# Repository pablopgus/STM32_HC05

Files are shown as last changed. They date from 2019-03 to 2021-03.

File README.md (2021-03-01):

# STM32_HC05
This is a PCB board designed in KiCAD which implements a STM32F746VGT6 microcontroller exposing the following pins and internal connections. All of the GPIO pins support timer peripheral output, for a more detailed view of the potential PIN function, check the STM32F7 datasheet using name as a reference. Please read [STM32F7 Reference page](https://www.st.com/en/microcontrollers-microprocessors/stm32f7-series.html) and [Getting Started Guide](https://www.st.com/resource/en/user_manual/dm00180213-getting-started-with-stm32cubef7-mcu-package-for-stm32f7-series-stmicroelectronics.pdf).

This board includes a [HC-05 Bluetooth module](https://components101.com/wireless/hc-05-bluetooth-module)  which exposes a serial port interface over bluetooth as a direct link with the microcontroller. The bluetooth module is switched on/off with a transistor switch controlled by a microcontroller pin. 

## Board Design
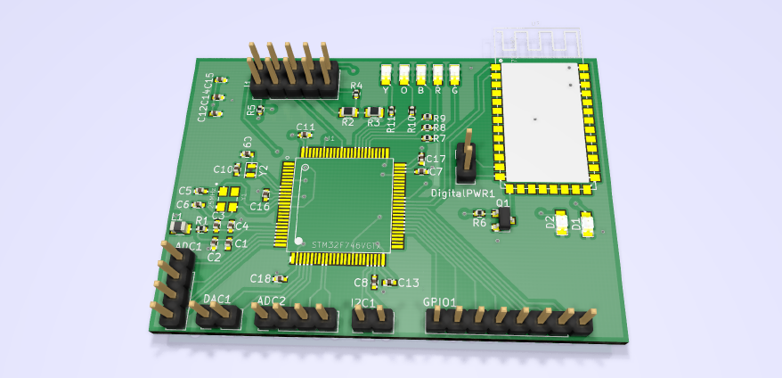
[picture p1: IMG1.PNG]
PCB Design


## Pinout
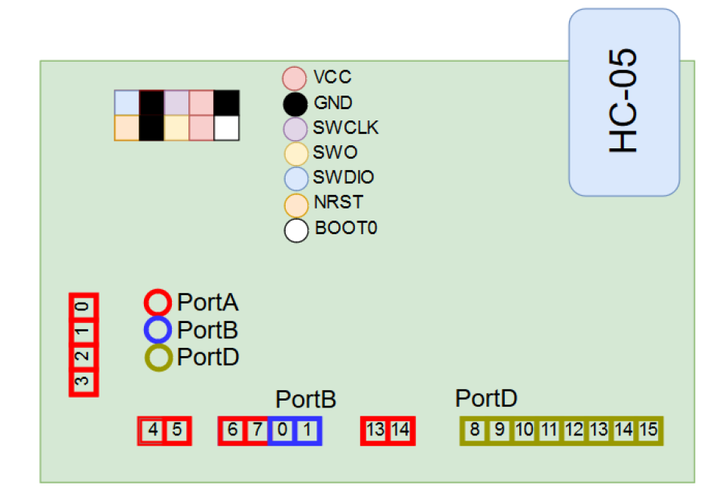
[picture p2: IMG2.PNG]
Pinout


## Pin Function

| Name | Pin | Extra Functions |
| :---: |:---:| :---: |
| PA0 | 22 | ADC0, UART4_TX, USART2_CTS |
| PA1 | 23 | ADC1, UART4_RX, USART2_RTS |
| PA2 | 24 | ADC2, USART2_TX |
| PA3 | 25 | ADC3, USART2_RX |
| PA4 | 28 | ADC4, USART2_CLK |
| PA5 | 29 | ADC5, SPI1_CLK |
| PA6 | 30 | ADC6, SPI1_MISO |
| PA7 | 31 | ADC7, SPI1_MOSI |
| PB0 | 34 | ADC8 |
| PB1 | 35 | ADC9 |
| PB10 | 46 | I2C2_CLK |
| PB11 | 47 | I2C2_SDA |
| PD8 | 55 | USART3_TX |
| PD9 | 56 | USART3_RX |
| PD10 | 57 | USART3_CLK |
| PD11 | 58 | USART3_CTS |
| PD12 | 59 | USART3_RTS |
| PD13 | 60 | |
| PD14 | 61 | |
| PD15 | 62 | |
| PD0 | 81 | Green LED |
| PD1 | 82 | Red LED |
| PD2 | 83 | Blue LED |
| PD3 | 84 | Orange LED |
| PD4 | 85 | Yellow LED |
| PC6 | 63 | HC-05 UART RX |
| PC7 | 64 | HC-05 UART TX |
| PC8 | 65 | HC-05 BT KEY |
| PE12 | 42 | Bluetooth Enable |

## Programming Interface
The programming and power port is located on the upper left section of the board. The flashing debugging must be performed using a ST-Link/v2 debugger or STM32FX evaluation board (Discovery, Nucleo, etc ...). LEDs are connected to GPIO (PD0-4), bluetooth module is connected to UART6 port and the bluetooth module on/off actuation is driven by GPIO PE12. Further information on programming and the specific pin functions can be found on the STM32F7 datasheet, and the HC-05 bluetooth module reference guide.

# Code Examples
The following 4 files form the required interface to program and operate the Bluetooth module via the UART peripheral of the STM32F7.
## bluetooth.h
```C
#ifndef __bluetooth_H
#define __bluetooth_H
#ifdef __cplusplus
 extern "C" {
#endif

/* Includes ------------------------------------------------------------------*/
#include "stm32f7xx_hal.h"
#include "stdlib.h"
#include <stdio.h>
#include <string.h>
#include "gpio.h"

void BT_isAlive(void);
void BT_setNameMixcell(void);
void BT_clearPaired(void);
void BT_setMaster(void);
void BT_setSlave(void);
void BT_setCOM(void);
void BT_Reset(void);	
void BT_Restore(void);	
void BT_SendTest(void);
void BT_CMode(void);
void BT_Init_UART(void);
	 
#ifdef __cplusplus
}
#endif
#endif /*__ bluetooth_H */
```
## bluetooth.c
```C
#include "bluetooth.h"

extern UART_HandleTypeDef UART;

extern char data_rx[32];
extern char rx_data[8];			/* Buffer used for UART */

void BT_isAlive(void)
{
	char data_tx[4] = "AT\r\n";
	memset(data_rx, 0x00, 32);
	HAL_UART_Transmit(&UART, (uint8_t *) data_tx, 4, 1000);
	HAL_UART_Receive(&UART, (uint8_t *) data_rx, 24, 1000);
}

void BT_setName(void)
{
	// TODO Set Bluetooth name: MY_NAME.
	char data_tx[17] = "AT+NAME=MY_NAME\r\n";
	memset(data_rx, 0x00, 32);
	HAL_UART_Transmit(&UART, (uint8_t *) data_tx, 17, 500);
	HAL_UART_Receive(&UART, (uint8_t *) data_rx, 24, 500);
}

void BT_setMaster(void)
{
	char data_tx[11] = "AT+ROLE=1\r\n";
	memset(data_rx, 0x00, 32);
	HAL_UART_Transmit(&UART, (uint8_t *) data_tx, 11, 500);
	HAL_UART_Receive(&UART, (uint8_t *) data_rx, 24, 500);
}

void BT_setSlave(void)
{
	char data_tx[11] = "AT+ROLE=0\r\n";
	memset(data_rx, 0x00, 32);
	HAL_UART_Transmit(&UART, (uint8_t *) data_tx, 11, 500);
	HAL_UART_Receive(&UART, (uint8_t *) data_rx, 24, 500);
}

void BT_Reset(void)
{
	char data_tx[10] = "AT+RESET\r\n";
	memset(data_rx, 0x00, 32);
	HAL_UART_Transmit(&UART, (uint8_t *) data_tx, 10, 500);
	HAL_UART_Receive(&UART, (uint8_t *) data_rx, 24, 500);
}

void BT_Restore(void)
{
	char data_tx[9] = "AT+ORGL\r\n";
	memset(data_rx, 0x00, 32);
	HAL_UART_Transmit(&UART, (uint8_t *) data_tx, 9, 500);
	HAL_UART_Receive(&UART, (uint8_t *) data_rx, 32, 500);
}

void BT_clearPaired(void)
{
	char data_tx[10] = "AT+RMAAD\r\n";
	memset(data_rx, 0x00, 32);
	HAL_UART_Transmit(&UART, (uint8_t *) data_tx, 10, 500);
	HAL_UART_Receive(&UART, (uint8_t *) data_rx, 24, 500);
}

void BT_setCOM(void)
{
	char data_tx[20] = "AT+UART=115200,0,0\r\n";
	memset(data_rx, 0x00, 32);
	HAL_UART_Transmit(&UART, (uint8_t *) data_tx, 20, 500);
	HAL_UART_Receive(&UART, (uint8_t *) data_rx, 24, 500);
}
```
## usart.h
```C
/**
  ******************************************************************************
  * File Name          : UART.h
  * Date               : 13/04/2015 14:34:07
  * Description        : This file provides code for the configuration
  *                      of the USART instances.
  ******************************************************************************
  *
  * COPYRIGHT(c) 2015 STMicroelectronics
  *
  * Redistribution and use in source and binary forms, with or without modification,
  * are permitted provided that the following conditions are met:
  *   1. Redistributions of source code must retain the above copyright notice,
  *      this list of conditions and the following disclaimer.
  *   2. Redistributions in binary form must reproduce the above copyright notice,
  *      this list of conditions and the following disclaimer in the documentation
  *      and/or other materials provided with the distribution.
  *   3. Neither the name of STMicroelectronics nor the names of its contributors
  *      may be used to endorse or promote products derived from this software
  *      without specific prior written permission.
  *
  * THIS SOFTWARE IS PROVIDED BY THE COPYRIGHT HOLDERS AND CONTRIBUTORS "AS IS"
  * AND ANY EXPRESS OR IMPLIED WARRANTIES, INCLUDING, BUT NOT LIMITED TO, THE
  * IMPLIED WARRANTIES OF MERCHANTABILITY AND FITNESS FOR A PARTICULAR PURPOSE ARE
  * DISCLAIMED. IN NO EVENT SHALL THE COPYRIGHT HOLDER OR CONTRIBUTORS BE LIABLE
  * FOR ANY DIRECT, INDIRECT, INCIDENTAL, SPECIAL, EXEMPLARY, OR CONSEQUENTIAL
  * DAMAGES (INCLUDING, BUT NOT LIMITED TO, PROCUREMENT OF SUBSTITUTE GOODS OR
  * SERVICES; LOSS OF USE, DATA, OR PROFITS; OR BUSINESS INTERRUPTION) HOWEVER
  * CAUSED AND ON ANY THEORY OF LIABILITY, WHETHER IN CONTRACT, STRICT LIABILITY,
  * OR TORT (INCLUDING NEGLIGENCE OR OTHERWISE) ARISING IN ANY WAY OUT OF THE USE
  * OF THIS SOFTWARE, EVEN IF ADVISED OF THE POSSIBILITY OF SUCH DAMAGE.
  *
  ******************************************************************************
  */
/* Define to prevent recursive inclusion -------------------------------------*/
#ifndef __usart_H
#define __usart_H
#ifdef __cplusplus
 extern "C" {
#endif

/* Includes ------------------------------------------------------------------*/
#include "stm32f7xx_hal.h"
#include "adc.h"
#include "stdlib.h"
#include "bluetooth.h"
	 
void MX_USART_UART_Init(void);
void HAL_UART_MspInit(UART_HandleTypeDef* huart);
void HAL_UART_MspDeInit(UART_HandleTypeDef* huart);
void receive_UART_action(void);
void send_UART_copy(void);
void send_back(char rx_data[8]);
void send_alive(void);

/* HC-05 BT driver. */
void BT_Config(void);
void BT_UART(void);
void send_data(void);

#ifdef __cplusplus
}
#endif
#endif /*__ usart_H */

/**
  * @}
  */

/**
  * @}
  */

/************************ (C) COPYRIGHT STMicroelectronics *****END OF FILE****/
```
## usart.c
```C
#include "usart.h"
#include "gpio.h"
#include <stdio.h>
#include <math.h>
#include "stdlib.h"
#include <string.h>

UART_HandleTypeDef UART;

char data_rx[32] = "";
extern char rx_data[8];			/* Buffer used for UART */
extern uint16_t INFO_TO_SEND[1024]; 	/* Buffer used for ADC */

/* USART6 init function */
void MX_USART_UART_Init(void)
{
  UART.Instance = USART6;
  UART.Init.BaudRate = 38400;
	UART.Init.WordLength = UART_WORDLENGTH_8B;
  UART.Init.StopBits = UART_STOPBITS_1;
  UART.Init.Parity = UART_PARITY_NONE;
  UART.Init.Mode = UART_MODE_TX_RX;
  UART.Init.HwFlowCtl = UART_HWCONTROL_NONE;
  UART.Init.OverSampling = UART_OVERSAMPLING_16;
	UART.Init.OneBitSampling = UART_ONEBIT_SAMPLING_DISABLED;
  UART.AdvancedInit.AdvFeatureInit = UART_ADVFEATURE_NO_INIT;
  HAL_UART_Init(&UART);
}

void HAL_UART_MspInit(UART_HandleTypeDef* huart)
{

  GPIO_InitTypeDef GPIO_InitStruct;
  if(huart->Instance==USART6)
  {
  /* USER CODE BEGIN USART_MspInit 0 */

  /* USER CODE END USART_MspInit 0 */
    /* Peripheral clock enable */
		__GPIOC_CLK_ENABLE();
    __USART6_CLK_ENABLE();
  
    /**USART6 GPIO Configuration    
    PC6     ------> USART6_TX
    PC7     ------> USART6_RX 
    */
    GPIO_InitStruct.Pin = GPIO_PIN_6|GPIO_PIN_7;
    GPIO_InitStruct.Mode = GPIO_MODE_AF_PP;
    GPIO_InitStruct.Pull = GPIO_PULLUP;
    GPIO_InitStruct.Speed = GPIO_SPEED_HIGH;
    GPIO_InitStruct.Alternate = GPIO_AF8_USART6;
    HAL_GPIO_Init(GPIOC, &GPIO_InitStruct);
		
  /* System interrupt init*/
    HAL_NVIC_SetPriority(USART6_IRQn, 0, 0);
    HAL_NVIC_EnableIRQ(USART6_IRQn);
  /* USER CODE BEGIN USART6_MspInit 1 */

  /* USER CODE END USART6_MspInit 1 */
  }

}

void HAL_UART_MspDeInit(UART_HandleTypeDef* huart)
{

  if(huart->Instance==USART6)
  {
  /* USER CODE BEGIN USART6_MspDeInit 0 */

  /* USER CODE END USART6_MspDeInit 0 */
    /* Peripheral clock disable */
    __USART6_CLK_DISABLE();
  
    /**USART6 GPIO Configuration    
    PC6     ------> USART6_TX
    PC7     ------> USART6_RX 
    */
    HAL_GPIO_DeInit(GPIOC, GPIO_PIN_6|GPIO_PIN_7);

    /* Peripheral interrupt DeInit*/
    HAL_NVIC_DisableIRQ(USART6_IRQn);

  /* USER CODE BEGIN USART6_MspDeInit 1 */

  /* USER CODE END USART6_MspDeInit 1 */
  }

}

/* USER CODE BEGIN 1 */
void BT_Init_UART()
{
	BT_UART();
}

void BT_Config(void)
{
	BT_Reset();
	HAL_Delay(1000);
	BT_isAlive();
	HAL_Delay(1000);
	BT_Restore();
	HAL_Delay(1000);
	BT_setName();
	HAL_Delay(1000);
	BT_setCOM();
	HAL_Delay(1000);
	BT_clearPaired();
	HAL_Delay(1000);
}

void BT_SendTest(void)
{
	BT_isAlive();
}

void BT_UART(void)
{
	HAL_UART_DeInit(&UART);
	
  UART.Instance = USART6;
  UART.Init.BaudRate = 115200;
  UART.Init.WordLength = UART_WORDLENGTH_8B;
  UART.Init.StopBits = UART_STOPBITS_1;
  UART.Init.Parity = UART_PARITY_NONE;
  UART.Init.Mode = UART_MODE_TX_RX;
  UART.Init.HwFlowCtl = UART_HWCONTROL_NONE;
  UART.Init.OverSampling = UART_OVERSAMPLING_16;
  HAL_UART_Init(&UART);
}

/* TX SECTION */
void send_alive()
{
	char data_tx[9] = "SM_ALIVE\n";
	memset(data_rx, 0x00, 32);
	HAL_UART_Transmit(&UART, (uint8_t *) data_tx, 9, 1000);
	receive_UART_action();
}

void send_data(void)
{
	// TODO: INFO_TO_SEND would be the char array to be send. 
	uint8_t * data;
	HAL_UART_Transmit(&UART, (uint8_t *)(INFO_TO_SEND), 16384, 10000);
}

void send_back(char rx_data[8])
{
		HAL_UART_Transmit(&UART, (uint8_t *)rx_data, 8, 1000);		
}

/* RX SECTION */
void receive_UART_action()
{
	int i = 0;
	while (i < 8)
	{
		rx_data[i] = 0x00;
		i++;
	}
	HAL_UART_Receive_IT(&UART, (uint8_t *)rx_data, 8);
}

void HAL_UART_RxCpltCallback(UART_HandleTypeDef *huart)
{
		// TODO: Reception complete.
}
```

# Success Stories
- [Sensing Cell-Culture Assays with Low-Cost Circuitry](https://www.nature.com/articles/s41598-018-27295-3)
- [An Empirical-Mathematical Approach for Calibration and Fitting Cell-Electrode Electrical Models in Bioimpedance Tests](https://www.mdpi.com/1424-8220/18/7/2354)
- [Remote Cell Growth Sensing Using Self-Sustained Bio-Oscillations](https://www.mdpi.com/1424-8220/18/8/2550)
- [Data-Analytics Modeling of Electrical Impedance Measurements for Cell Culture Monitoring](https://www.mdpi.com/1424-8220/19/21/4639)
- [Electrical Modeling of the Growth and Differentiation of Skeletal Myoblasts Cell Cultures for Tissue Engineering](https://www.mdpi.com/1424-8220/20/11/3152)

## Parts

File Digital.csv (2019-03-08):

PCB ID | Footprint | Cantidad | ID
R7,R8,R9,R10,R11,R1 | SMD_0402 | 6 | 330
R2,R3 | SMD_0805 | 2 | 33K
DAC1,DigitalPWR1,I2C1 | Header | 3 | Conn_01x02
ADC1,ADC2 | Header | 2 | Conn_01x04
GPIO1 | Header | 1 | Conn_01x08
J1 | Header | 1 | Conn_02x05_Odd_Even_MountingPin
U1 | LQFP100 | 1 | STM32F746VGT6
C8,C7 | SMD_0402 | 2 | 2.2uF
C17,C16,C15,C14,C13,C12,C11,C18,C4,C2 | SMD_0402 | 10 | 100nF
C6,C5 | SMD_0402 | 2 | 22nF
C3,C1 | SMD_0402 | 2 | 1uF
C9,C10 | SMD_0402 | 2 | 6pF
Y1 | Crystal_SMD_2520-4pin_2.5x2.0mm | 1 | 25MHz
Y2 | Crystal_SMD_5032-2pin_5.0x3.2mm | 1 | 32kHz
L1 | SMD_0805 | 1 | 22uH
R5,R6,R4 | SMD_0402 | 3 | 33K
Q1 | SOT-23 | 1 | BSS138
U2 | HC05 | 1 | MOUDLE-BLUETOOTH-HC-05(34P-27X13MM)
G, D1, D2 | SMD_0805 | 3 | Green LED
O | SMD_0805 | 1 | Orange LED
R | SMD_0805 | 1 | Red LED
Y | SMD_0805 | 1 | Yellow LED
B | SMD_0805 | 1 | Blue LED

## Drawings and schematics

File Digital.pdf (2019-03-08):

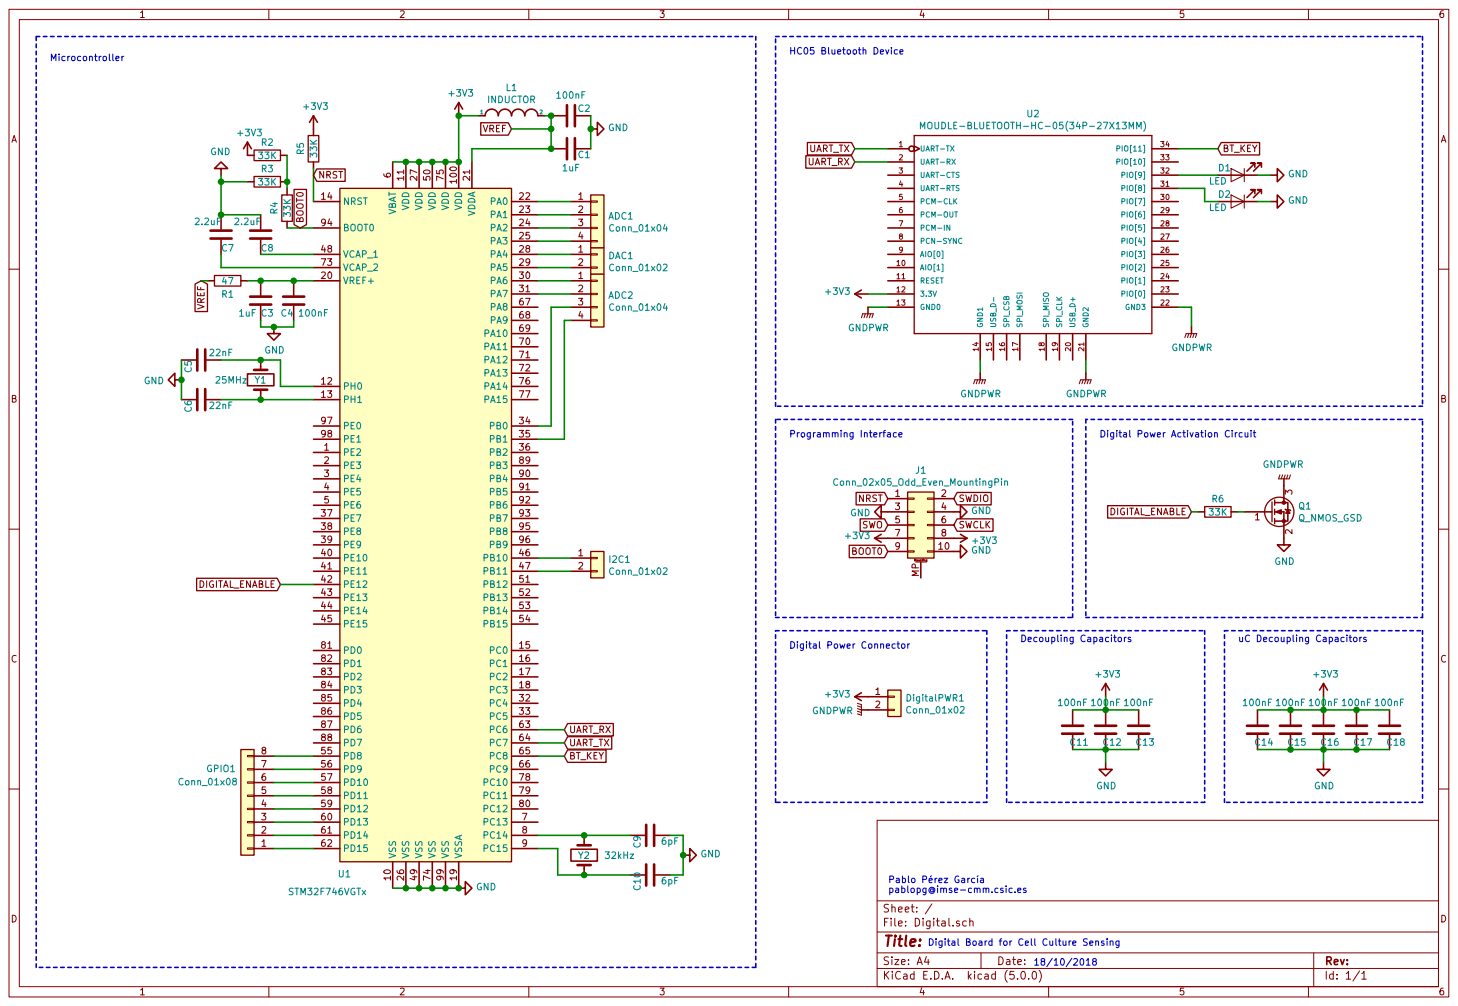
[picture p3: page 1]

6 VCAP_1 48 VCAP_2 73 VDD 100 VDD 11 VDD 27 VDD 50 VDD 75 VDDA 21 VREF+ 20 VSS 10 VSS 26 VSS 49 VSS 74 VSS 99 VSSA U1 19 STM32F746VGTx GND

Digital Board for Cell Culture Sensing Pablo Pérez García
File: Digital.sch Sheet: /
Id: 1/1 Title:

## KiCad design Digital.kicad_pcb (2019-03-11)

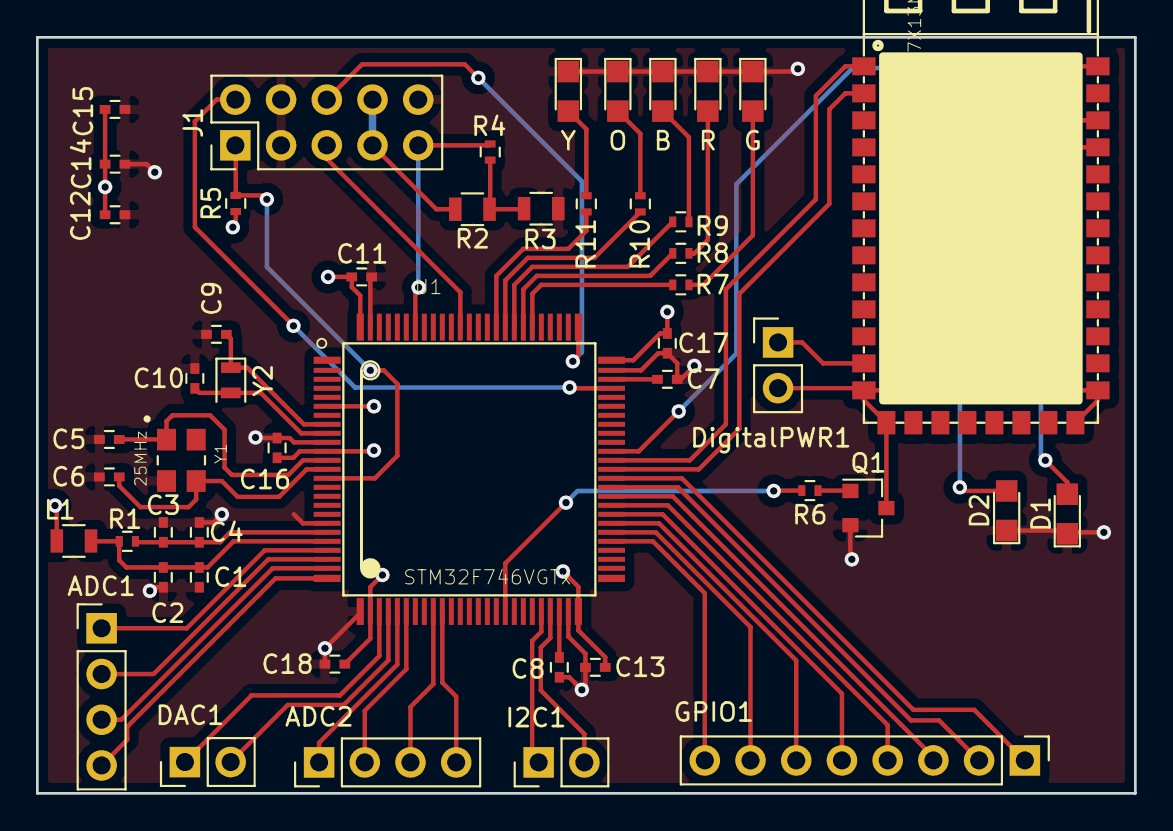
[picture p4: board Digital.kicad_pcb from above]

Board: 4 copper layers, 61.0 x 42.0 mm, 49 parts (0 on the bottom side), 54 nets.

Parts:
ADC1, ADC2: Conn_01x04; Pin_Header_Straight_1x04_Pitch2.54mm
B: LED; LED_0805
C1, C3: 1uF; C_0402
C2, C4, C11, C12, C13, C14, C15, C16, C17, C18: 100nF; C_0402
C5, C6: 22nF; C_0402
C7, C8: 2.2uF; C_0402
C9, C10: 6pF; C_0402
D1, D2: LED; LED_0805
DAC1: Conn_01x02; Pin_Header_Straight_1x02_Pitch2.54mm
DigitalPWR1: Conn_01x02; Pin_Header_Straight_1x02_Pitch2.54mm
G: LED; LED_0805
GPIO1: Conn_01x08; Pin_Header_Straight_1x08_Pitch2.54mm
I2C1: Conn_01x02; Pin_Header_Straight_1x02_Pitch2.54mm
J1: Conn_02x05_Odd_Even_MountingPin; Pin_Header_Straight_2x05_Pitch2.54mm
L1: INDUCTOR; L_0805
O: LED; LED_0805
Q1: Q_NMOS_GSD; SOT-23
R: LED; LED_0805
R1, R7, R8, R9, R10, R11: 47; R_0402
R2, R3: 33K; R_0805
R4, R5, R6: 33K; R_0402
U1: STM32F746VGTx; LQFP100
U2: MOUDLE-BLUETOOTH-HC-05(34P-27X13MM); HC05
Y: LED; LED_0805
Y1: 25MHz; OSCCC320X250X60N
Y2: 32kHz; Crystal_SMD_2012-2pin_2.0x1.2mm

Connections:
+3V3: C11.2, C12.2, C13.2, C14.2, C15.2, C16.2, C17.2, C18.2, DigitalPWR1.1, J1.7, J1.8, L1.1, R2.2, R5.1, U1.6, U1.11, U1.27, U1.50, U1.75, U1.100, U2.12
BOOT0: J1.9, R4.2, U1.94
BT_KEY: U1.65, U2.34
DIGITAL_ENABLE: R6.2, U1.42
GND: B.1, C1.2, C2.2, C3.1, C4.1, C5.1, C6.1, C7.1, C8.1, C9.2, C10.2, C11.1, C12.1, C13.1, C14.1, C15.1, C16.1, C17.1, C18.1, D1.1, D2.1, G.1, J1.3, J1.4, J1.10, O.1, Q1.2, R.1, R3.2, U1.10, U1.19, U1.26, U1.49, U1.74, U1.99, Y.1, Y1.2
GNDPWR: DigitalPWR1.2, Q1.3, U2.13, U2.14, U2.21, U2.22
NRST: J1.1, R5.2, U1.14
unnamed: ADC1.1, U1.22
unnamed: ADC1.2, U1.23
unnamed: ADC1.3, U1.24
unnamed: ADC1.4, U1.25
unnamed: ADC2.1, U1.30
unnamed: ADC2.2, U1.31
unnamed: ADC2.3, U1.34
unnamed: ADC2.4, U1.35
unnamed: B.2, R9.2
unnamed: C3.2, C4.2, R1.1, U1.20
unnamed: C5.2, U1.12, Y1.1
unnamed: C6.2, U1.13, Y1.3
unnamed: C7.2, U1.73
unnamed: C8.2, U1.48
unnamed: C9.1, U1.8, Y2.1
unnamed: C10.1, U1.9, Y2.2
unnamed: D1.2, U2.32
unnamed: D2.2, U2.31
unnamed: DAC1.1, U1.28
unnamed: DAC1.2, U1.29
unnamed: GPIO1.1, U1.62
unnamed: GPIO1.2, U1.61
unnamed: GPIO1.3, U1.60
unnamed: GPIO1.4, U1.59
unnamed: GPIO1.5, U1.58
unnamed: GPIO1.6, U1.57
unnamed: GPIO1.7, U1.56
unnamed: GPIO1.8, U1.55
unnamed: G.2, R7.2
unnamed: I2C1.1, U1.46
unnamed: I2C1.2, U1.47
unnamed: O.2, R10.2
unnamed: Q1.1, R6.1
unnamed: R2.1, R3.1, R4.1
unnamed: R7.1, U1.81
unnamed: R8.1, U1.82
unnamed: R.2, R8.2
unnamed: R9.1, U1.83
unnamed: R10.1, U1.84
unnamed: R11.1, U1.85
unnamed: R11.2, Y.2
SWCLK: J1.6, U1.76
SWDIO: J1.2, U1.72
SWO: J1.5, U1.89
UART_RX: U1.63, U2.2
UART_TX: U1.64, U2.1
VREF: C1.1, C2.1, L1.2, R1.2, U1.21

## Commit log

2019-03-08 Initial Commit. Alpha version.
    [Digital-B.Cu.gbl, Digital-B.Mask.gbs, Digital-B.Paste.gbp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]
2019-03-11 Footprint changed in Y1
    [Digital.kicad_pcb, Digital.sch]
